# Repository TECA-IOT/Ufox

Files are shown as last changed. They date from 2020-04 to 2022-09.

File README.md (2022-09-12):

# 1. Ufox devkit Sigfox RC4
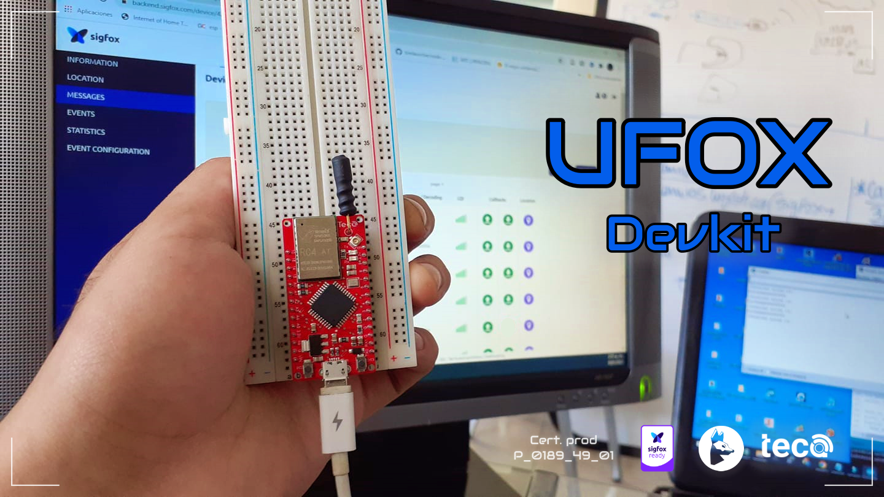
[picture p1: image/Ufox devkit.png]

Kit de desarrollo Sigfox para región RC4: 
-Argentina, Chile, Colombia, Costa Rica El Salvador, Panamá, Guatemala, Honduras, Nicaragua, Panama, Perú, Trinidad & Tobago, Uruguay, Paraguay.
Asia pacifico: 
Australia, Hong Kong, Indonesia, Malasia, Nueva Zelanda, Singapure, Taiwán, Thailandia.

## 1.1 Visita la Wiki Ufox: Documentación y ejemplos avanzados
`<link>` : <https://github.com/TECA-IOT/Ufox/wiki>
### 1.1.1 API librería ufox.h
`<link>` : <https://github.com/TECA-IOT/Ufox/wiki/API>
### 1.1.2 Manual Técnico
`<link>` : <https://github.com/TECA-IOT/Ufox/wiki/Manual-T%C3%A9cnico>
### 1.1.3 Enviar múltiples variables en mensaje sigfox con función sprintf
`<link>` : <https://github.com/TECA-IOT/Ufox/wiki/Funci%C3%B3n-Sprintf>
### 1.1.4 Librería Fritzing
`<link>` : <https://github.com/TECA-IOT/Ufox/wiki/Libreria-de-ufox-para-Fritzing>
### 1.1.4 Guía de inicio rápido
`<link>` : <https://github.com/TECA-IOT/Ufox/wiki/Gu%C3%ADa-de-inicio-r%C3%A1pido>

### 1.1.5 SHIELD UFOX INFORMACION:
`<link>` : <https://github.com/TECA-IOT/Shield-Ufox>

## 1.2 Caracteristicas

- Microcontrolador Atmega32U4 USB y Modem Wisol WSSFM10R4 RC4 .
- Programable con Arduino IDE (compatible con pines de arduino Leonardo, ProMicro, Micro, y otras placas arduino basadas en el micro atmega32U4).
- Incluye una antena interna helicoidal  de 3 Dbi y opcionalmente un conector  UFL para antenas externas. (se recomienda previamente desoladar la antena helicoidal para su uso). 
- Alimentación desde fuente USB 5V con voltaje de operación interno de 3.3V.
- Ideal para desarrollar prototipos y aplicaciones de forma rapida y sencilla, incluye un microcotrolador Atmega32U4  compatible con arduino.
- Cuenta con un regulador de voltaje de 3.3V AMS1117  suministra  hasta 1 amperio de corriente.
- Diseño compacto, seguro y de bajo consumo
- Comunicación serial por Hardware (Serial1 Arduino) dedicado exclusivamente para comunicacion con modem Wisol.
- Reset de modulo Wisol Conectado al Pin "12" Arduino. 
- Botón de proposito general programable en el pin "13" Arduino
- Pines Digitales, Analogicos, PWM, comunicacion SPI, I2C,Interrupcion externa, Serial.
- informacion acerca de arduino leonardo: 
`<link>` : <https://store.arduino.cc/usa/leonardo>

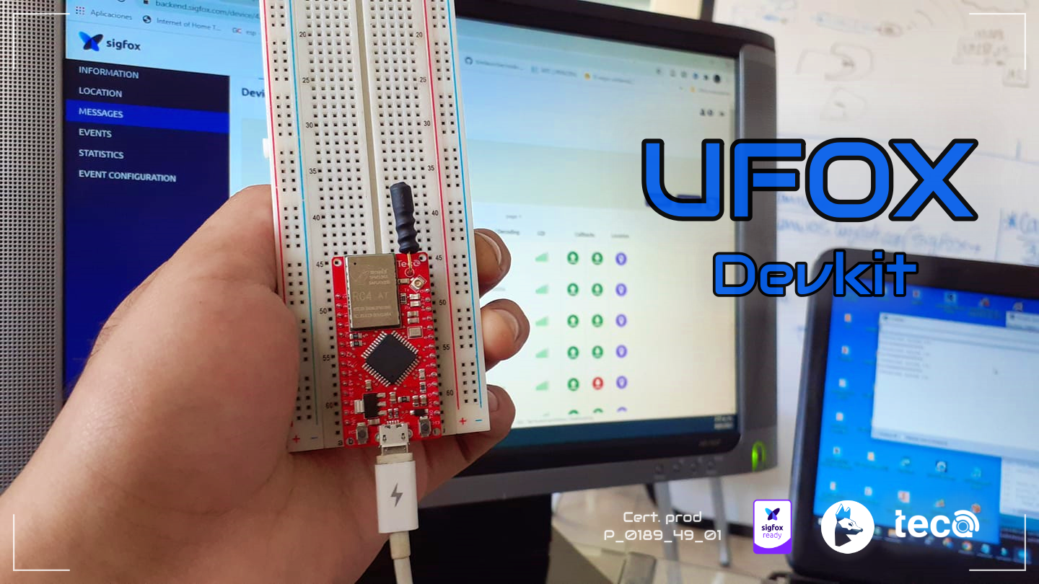
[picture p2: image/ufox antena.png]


## 1.3 Caracteristicas 
### 1.3.1 Electricas 

| Descripcion (1*)| Unidad |
| --- | --- |
| Voltaje entrada USB (Conector micro USB)|  5 Voltios |  
| Voltaje Mínimo entrada (Pin VIN) |  3.7 Voltios |  
| Voltaje Máximo  entrada (Pin VIN) |  9 Voltios |  
| Corriente máxima | 1A |
| Voltaje de funcionamiento interno típico  |  3.3 Voltios  | 

| Descripcion (2*)| Unidad |
| --- | --- |
| Voltaje Máximo absoluto entrada (Pin 3.3V) |  4 Voltios |  
| Voltaje Mínimo absoluto entrada (Pin 3.3V) |  2.7 Voltios  |  

- Notas(*)
- (1*) Referente a la Entrada de voltaje por el Pin "VIN" o por el conector micro USB. Este voltaje ingresa por el regulador interno, el regulador suministrara a su salida 3.3 Voltios alimentando a toda la electrónica interna. El voltaje regulado se ve reflejado en el Pin "3.3V".
- (2*) Referente a la entrada de voltaje en el Pin "3.3V" para el  caso donde no exista entrada de voltaje por el pin "VIN". Este voltaje es suministrado sin proteccion directamente a toda la electronica interna. Esta forma de alimentar puede ser útil cuando se requiera emplear baterias. (Se recomienda agregar un diodo en serie)

### 1.3.2 Radiofrecuencia
| Descripcion | Unidad |
| --- | --- |
| Antena helicoidal | 3 DBi |
| Frec. Uplink | 920.8 MHz |
| Frec. Downlink | 922.3 MHz |
| Data rate | 600bps |
| Potencia RF | +22dbm 0,2045W máx |
| Modulación | DBPSK |
| Técnica de transmisión | FHSS |
| Técnologia de transmisión | UNB (Ultra narrow band) - Sigfox |
| Canales de transmisión | 54 canales (9 macro-canales x 6 micro-canales) |

## 1.4 Descripcion de pines Ufox

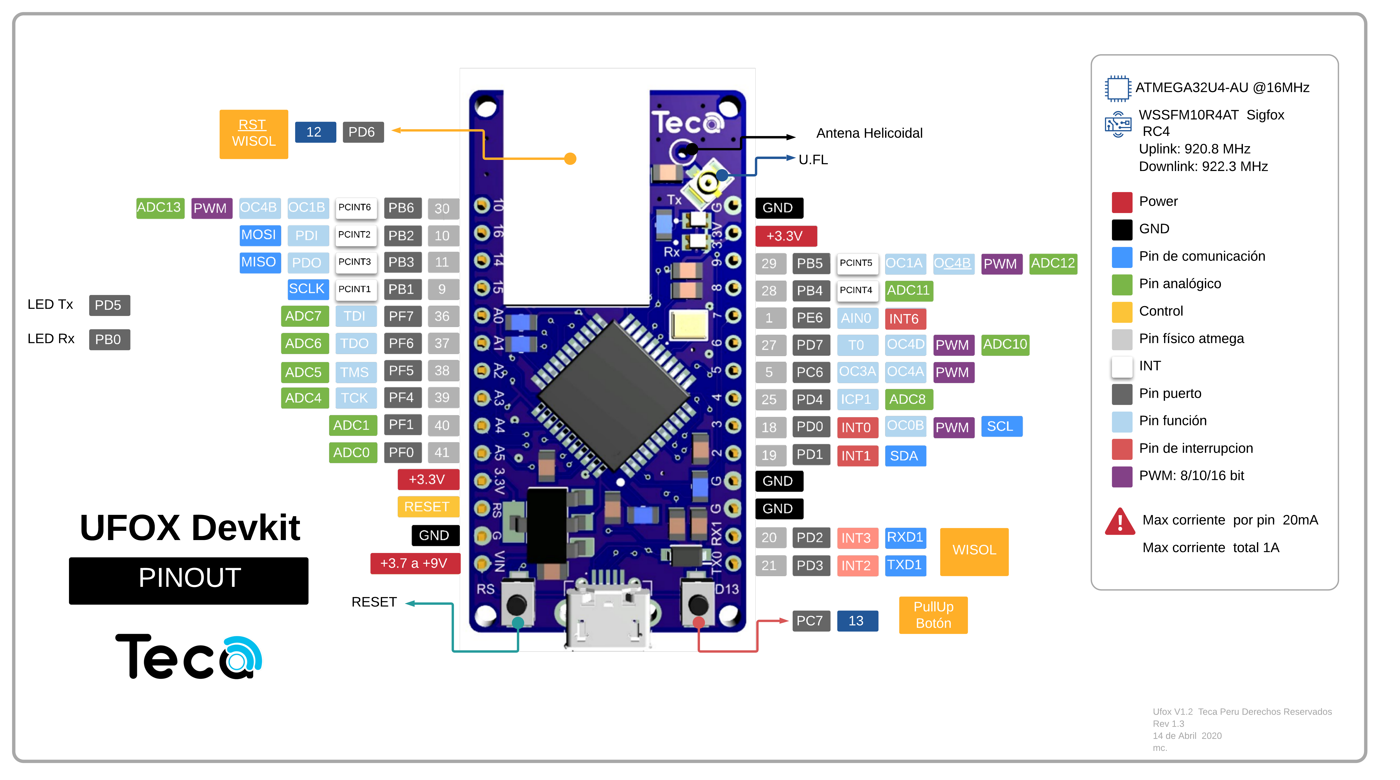
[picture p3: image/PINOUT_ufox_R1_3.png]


# 2. Cargar un Sketch a Ufox
- Enchufe el cable usb con el conector micro usb de Ufox, luego conectar a su PC
- Espere a que su PC  reconosca a Ufox (el reconocimiento es instantaneos para SO Window ,7,8,10).
- Abra el Ide Arduino.
- Puede cargar un  ejemplo de inicio  como el siguiente:

## 2.1 Blink Ufox
Ufox dispone de 2 led de señalizacion Serial Tx y RX, el usuario puede hacer uso de estos led, en este ejemplo se muestra como hacer uso de ellos.

```javascript

int RXLED = 17;  // El RXLED (AZUL) tiene un pin Arduino definido con numero 17

void setup()
{
  pinMode(RXLED, OUTPUT);  //LED RX como salida
}

void loop()
{
  digitalWrite(RXLED, LOW);   // encender RXLED 
  TXLED0;                   //  apagar TXLED
  delay(500);                 // Esperar un segundo
  digitalWrite(RXLED, HIGH);    // apagar el RXLED
  TXLED1;                     //TXLED macro, encender TXLED 
  delay(500);                 // Esperar un segundo
}
```

- Selecciones la placa Arduino Leonardo y seleccion el puerto COM detectado en su PC.
- Y cargue el sketch.

blink ufox

## 2.2 Comuncación Serial con modem Wisol
*El modem Wisol WSSFM10R4AT puede comunicarse mediante puerto serial1 a 9600 baudios, con una sintaxis definida con comando "AT", puede consultar mas informacion de comandos en la hoja de datos (datasheet). El modem trabaja a una frecuencia de 920MHZ Uplink y 922 Dowlink. Consulte mas informacionde como activar el mdem en la platafoma de sigfox o con su operador sigfox Local : Aqui 

```javascript
void setup() {
  Serial.begin(9600);
  Serial1.begin(9600);
}

void loop() {
   while (Serial.available()) {
    Serial1.write(Serial.read());
  }
  while (Serial1.available()) {
    Serial.write(Serial1.read());
  }
  
}
```

- Una vez cargado el sketch abra la terminal serial a 9600 baudios, seleccionar la opcion "Nueva línea".
- Escribir el comando "AT",presionar  enter, y a continuacion el chip wisol respondera con un "Ok"  
- Comandos de interes:
- ID:          AT$I=10
- PAC:         AT$I=11
- Voltaje:     AT$V?
- Temperatura: AT$T?

COMANDOS AT UFOX

## 2.3 Enviar mensaje sigfox mediante comandos AT
Enviar un mensaje a backend sigfox sera el siguiente: 255 decimal, SIGA LA SECUENCIA DE COMANDOS SIGUIENTE:
- AT$GI?
- AT$RC
- AT$SF=FF

COMANDOS AT UFOX SEND

## 2.4 Cómo registrar dispositivos a la red Sigfox
-  Obtenga un dispositivo SIGFOX ReadyTM (hardware).
- Obtenga el par de código ID/PAC de los dispositivos (extraible en el modem del dispositivo).
- Firme un contrato de suscripción con SIGFOX.
- Obtenga el inicio de sesión de SIGFOX Cloud (Backend Sigfox).
- Registre sus objetos con ID / PAC.
 Sus dispositivos están listos para la comunicación.
 
 ### Activación por Buy Sigfox
 - Disponible sólo para paises de: Colombia, Ecuador, Uruguay, Costa Rica, El Salvador, Panamá, 
 - Ingresar a la pagina  Buy Sigfox, Activate my devkit, Seleccionar su País e introducir los codigos ID y PAC: `<link>` : <https://buy.sigfox.com/activate> 
 
 ### Activación por contrato directo:
 - Para el resto de Paises. Contactarse por nuestro correos:  <gerencia.tecaperu@gmail.com> ó   nuestra pagina web <https://teca.pe> ó redes sociales <https://www.facebook.com/TecaIoTPeru>
 
#### 2.4.1 GLOSARIO
- ID : Identificador del dispositivo de 4 bytes (Es único)
- PAC :Código de autorización de transferencia de 8 bytes (Válido una vez). PAC es el certificado de propiedad del objeto, es requerido por la plataforma SIGFOX para validar las solicitudes de registro / transferencia de equipos. Una vez utilizado, la validez del código expira y se asigna un nuevo código.
- El PAC se proporciona en la venta del dispositivo (EXTRAIBLE DEL MODULO RF)
 - Ejemplo: 006D8AF2; 10708756FE9515D5  

# 3. LIBRERÍA UFOX ARDUINO | librería Sigfox
La libreria ufox incorpora una serie de funciones y metodos que simplifican la conexion a la red de sigfox. Instale la libreria Ufox  en el IDE de arduino descargando este repositorio, existen diversos modos de instalar libreria externas, 
## 3.1 Instalación
### 3.1.1 Opción 1: 
- Descomprima este repositorio descargado en formato .ZIP y copie la carpeta dentro de :  [Unidad]:\Users\[usuario]\Documents\Arduino\libraries
### 3.1.2 Opción 2: 
- Desde el mismo IDE Arduino dirijase a Programa, Incluir  Libreria, Añadir biblioteca  .ZIP . Localice el repositorio descargado y abrir.
- Una vez instalado recargue el  Ide arduino y podra ver que la libreria y ejemplo se muestran: 
### 3.1.3 Opción 3:
- Abrir el IDE Arduino, y desde el gestor de descargas de Librerias de Arduino descargar buscar "ufox" y descargarlo.
descargar libreria ufox

## 3.2 Enviar un Mensaje Simple con librería Ufox.h

En este ejemplo puede enviar un mensaje numérico cada vez que el botón 13 (ubicado al lado derecho del devkit), es presionado. Tener en consideración que los mensajes Sigfox son enviados en formato de hexagesimales con un tamaño  máximo de 12 bytes de carga útil (Payload), todos los valores numéricos serán convertidos a valores hexagesimales de forma automatica por librería. Elija el ejemplo llamado "Simple_uplink". 
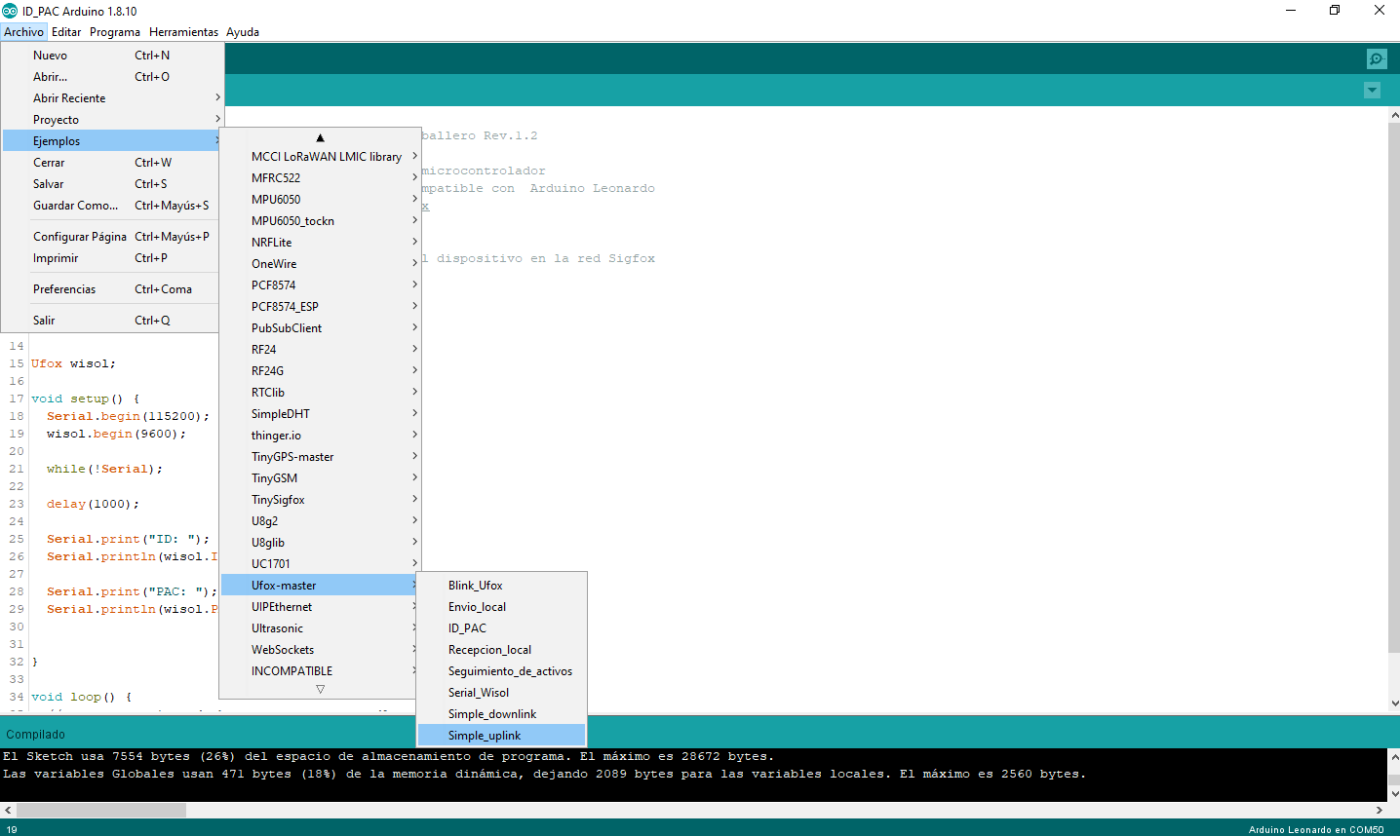
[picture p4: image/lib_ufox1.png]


```javascript
#include <Ufox.h>

#define btn   13
#define RXLED  17 

Ufox wisol;

void setup() {
  pinMode(btn,INPUT);
  pinMode(RXLED,OUTPUT);
  
  Serial.begin(115200);
  wisol.begin(9600);

  while(!Serial);  //comentar si usará una fuente de energía externa

 Serial.println("-Presione botón 13-");
}

void loop() {
  
  if(digitalRead(btn)==0){

    digitalWrite(RXLED,LOW);
    wisol.RST();
    
    uint32_t valor =random(0,15);
    Serial.println(wisol.SEND(valor));

    //String valor2 ="10";
    //Serial.println(wisol.SEND(valor2));
    
    digitalWrite(RXLED,HIGH);
    wisol.SLEEP();
    delay(3000);
    Serial.println("-Presione botón 13-");
  }  
}
```

###

###
- La información podrá vizualizarse en el backend de Sigfox. Usted previamente debe tener asociado a su cuenta el devkit Ufox con un contrato de conectividad. Se mostrara el ID de su dispositivo asociado y el nuevo codigo PAC que has sido generado tras la activación del contrato.
- El Backend de Sigfox es la plataforma para poder gestionar las conexiones de sus dispositivos. La configuración mas importante a consideracion son los Callbacks, donde podra redireccionar los mensajes por medio de HTTP o HTTPS a otros servidores, o tambien redireccionarlos a AWS IOT Core, Azure e IBM.

Simple uplink Ufox - backend sigfox

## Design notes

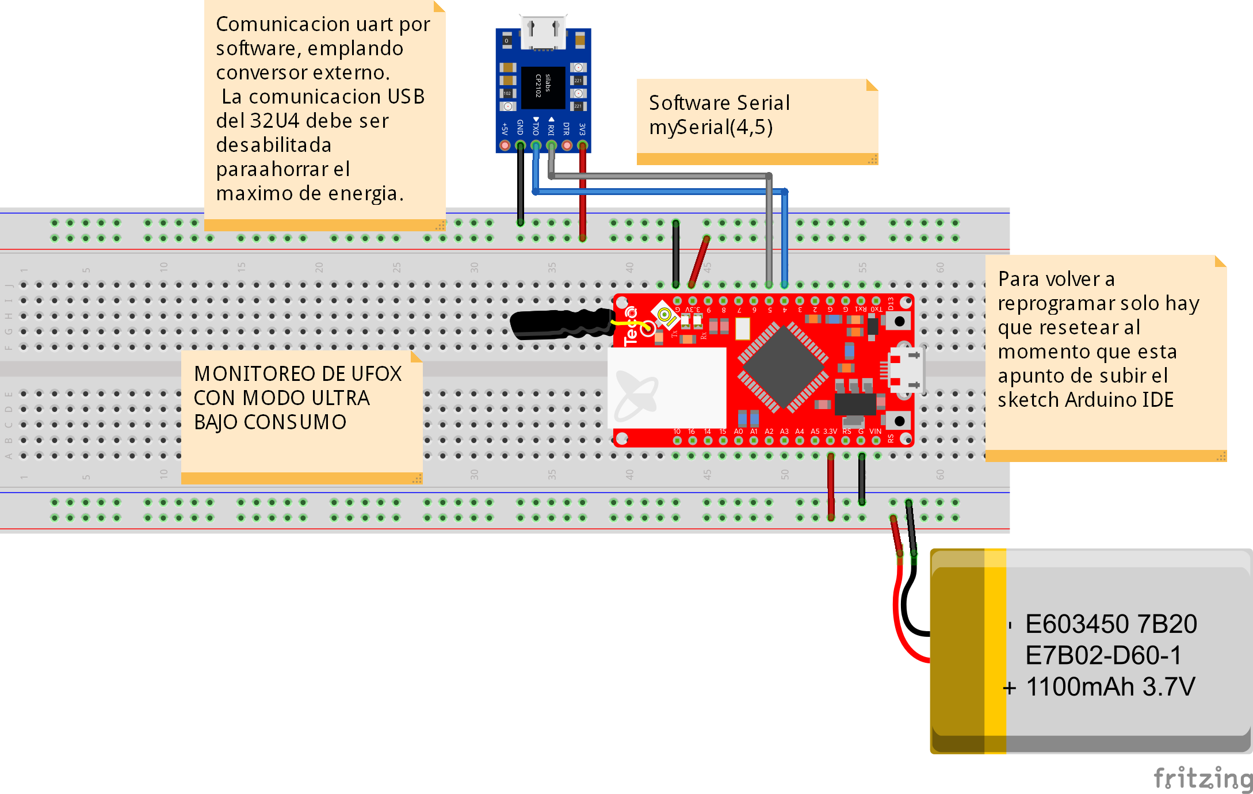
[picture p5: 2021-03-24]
image/ufox_lowpower_battery_bb.png

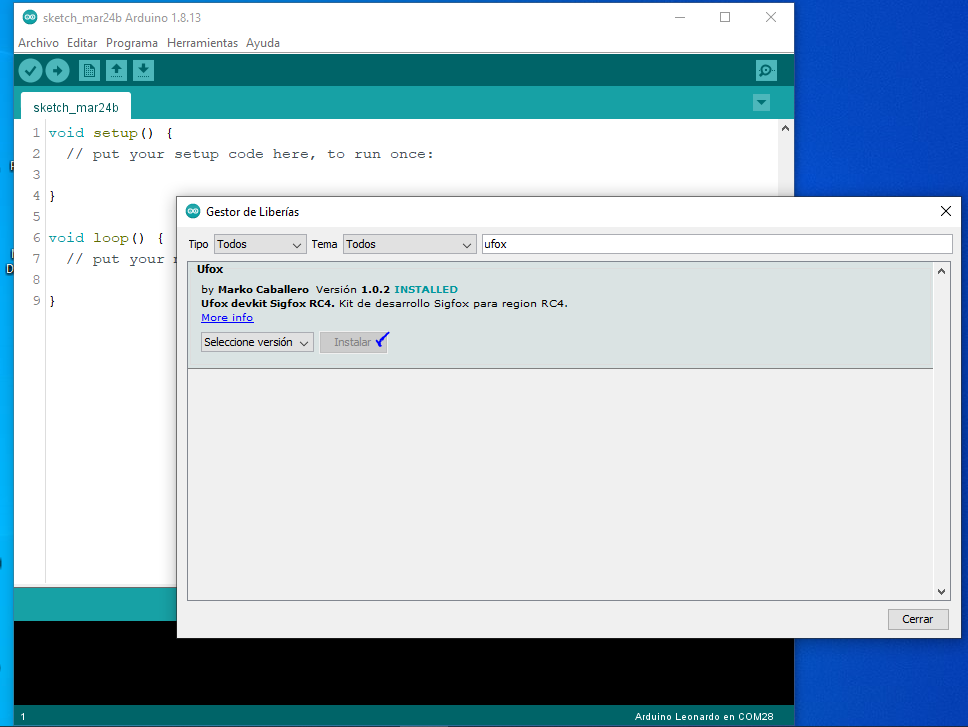
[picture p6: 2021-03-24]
image/ufox descargar lib.PNG

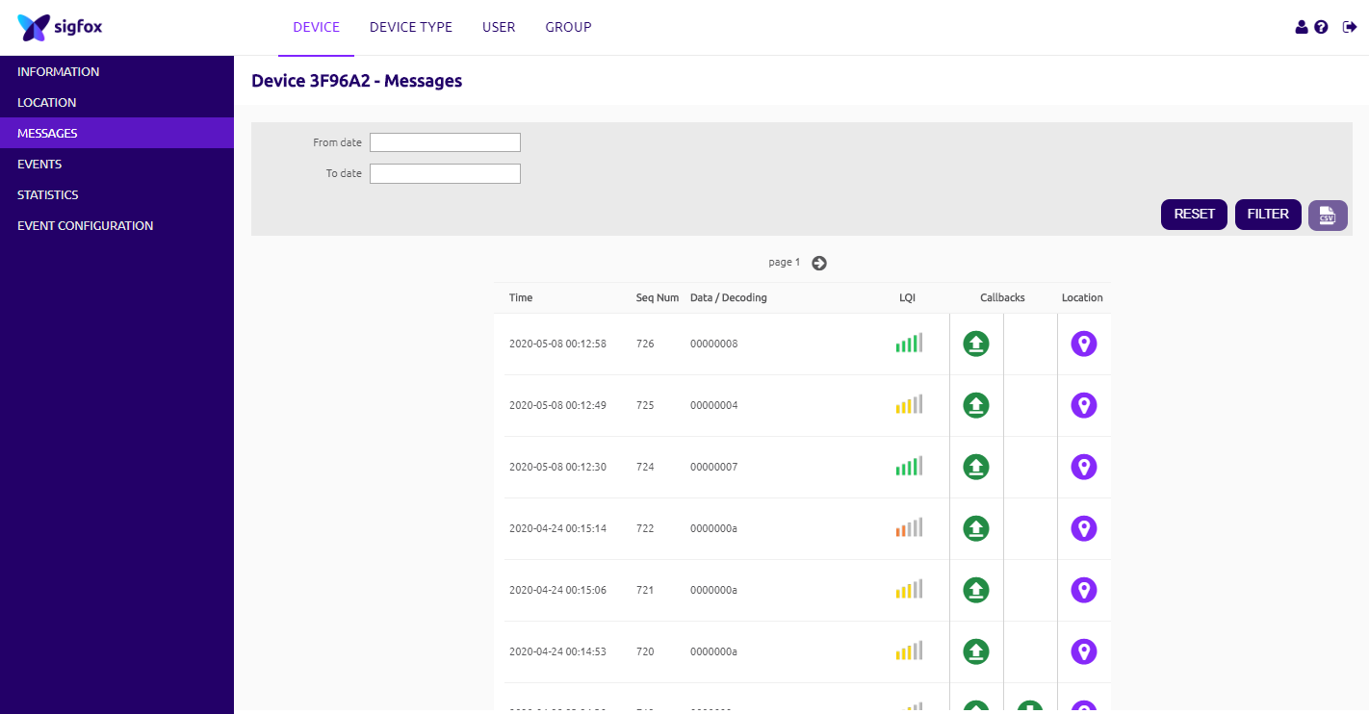
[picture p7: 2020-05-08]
image/wewe.png

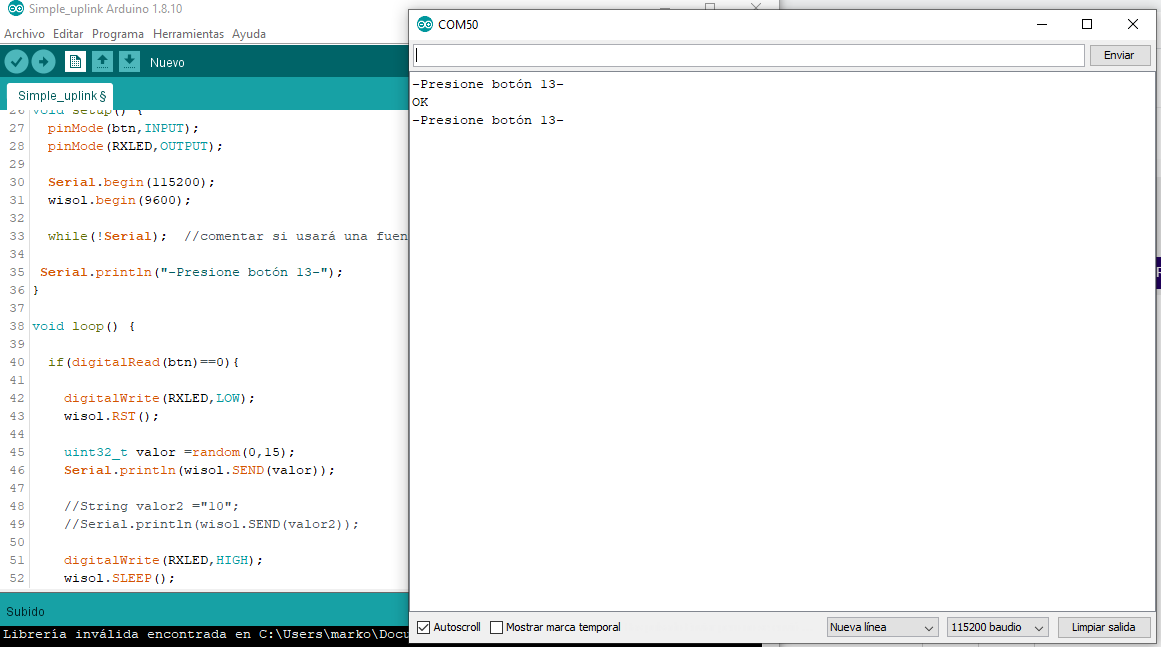
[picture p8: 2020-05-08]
image/qwrw.PNG

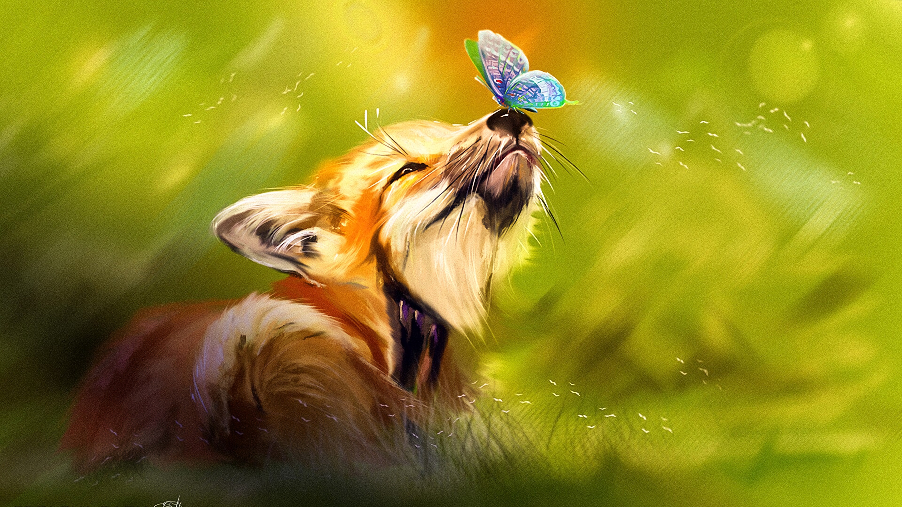
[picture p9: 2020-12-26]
image/Ufox lib.jpg

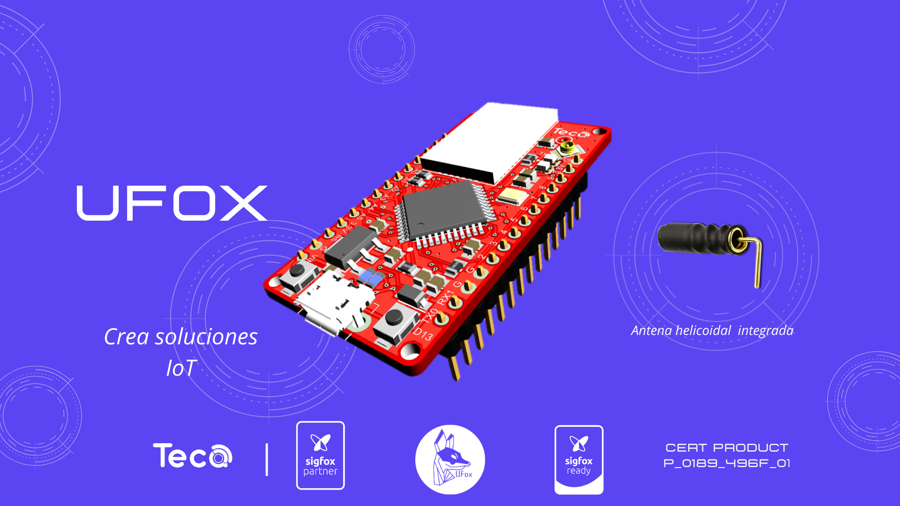
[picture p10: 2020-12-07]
image/ufox antena - copia.png

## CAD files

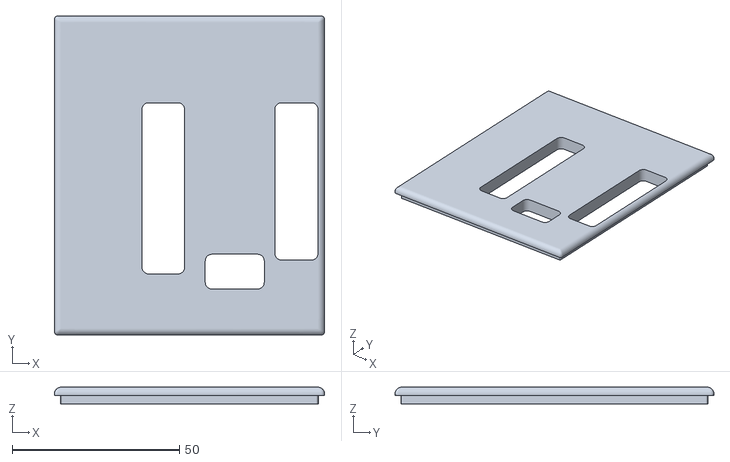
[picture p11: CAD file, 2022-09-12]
Case 3D/VERSION 1.0/STL/TAPA CASE UFOX.stl
80.8 x 95.4 x 5.00

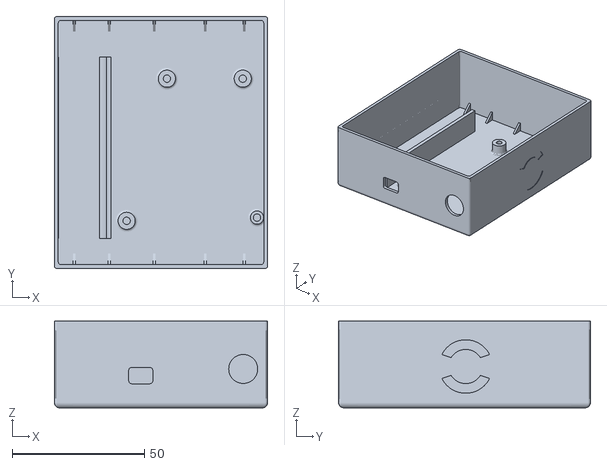
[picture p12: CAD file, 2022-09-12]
Case 3D/VERSION 1.0/STL/CASE UFOX.stl
80.8 x 95.4 x 32.8

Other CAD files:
Case 3D/VERSION 1.0/EDITABLES/CASE UFOX.ipt
Case 3D/VERSION 1.0/EDITABLES/TAPA CASE UFOX.ipt

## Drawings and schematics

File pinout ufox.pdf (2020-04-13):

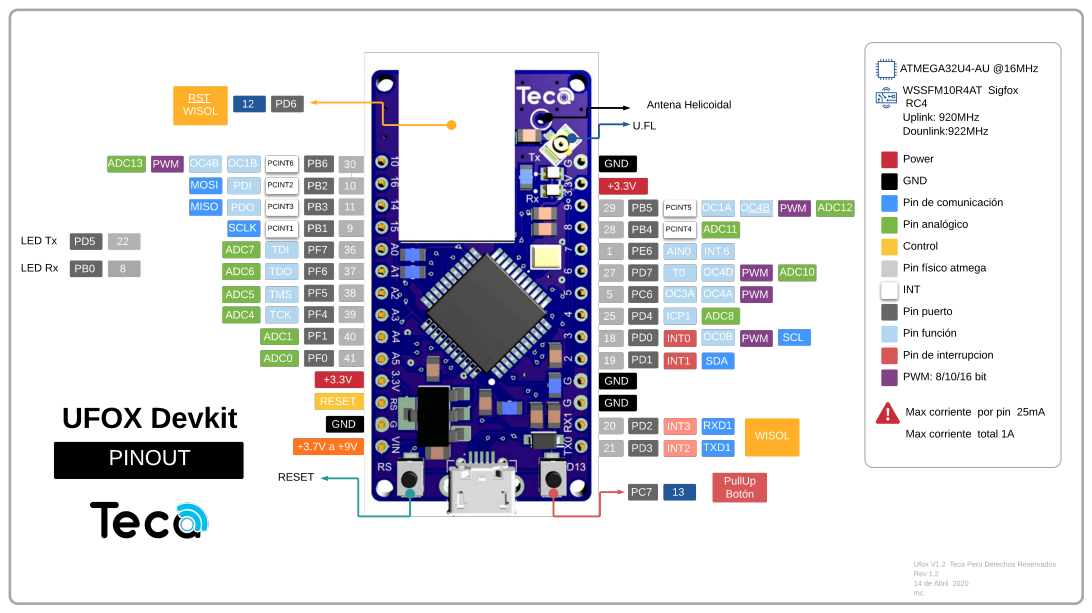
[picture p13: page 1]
RESET; UFOX Devkit; PINOUT; RST WISOL; WISOL; PullUp; Botón; ATMEGA32U4-AU @16MHz; WSSFM10R4AT Sigfox RC4 Uplink: 920MHz Dounlink:922MHz; Antena Helicoidal; LED Tx; LED Rx

Power
GND
Pin de comunicación
Pin analógico
Control
Pin físico atmega
INT
Pin puerto
Pin función
Pin de interrupcion
PWM: 8/10/16 bit

Max corriente por pin 25mA
Max corriente total 1A

Ufox V1.2 Teca Peru Derechos Reservados
Rev 1.2
14 de Abril 2020

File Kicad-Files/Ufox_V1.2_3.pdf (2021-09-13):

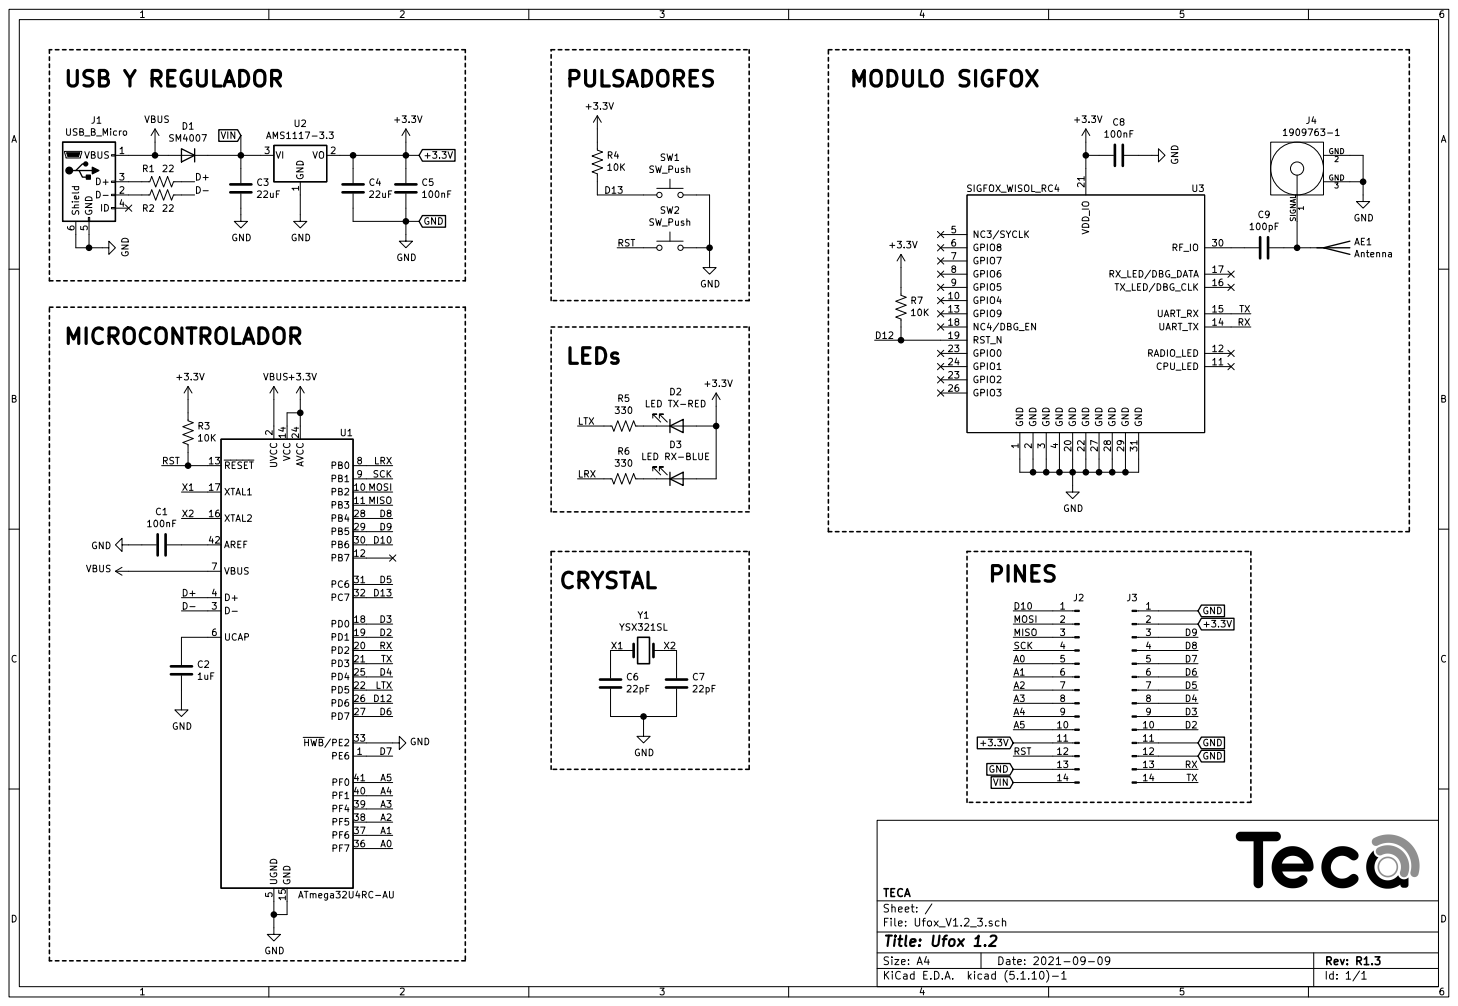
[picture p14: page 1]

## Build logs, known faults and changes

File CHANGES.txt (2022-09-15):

1.2
    * Uso para modem WSSFM10R4 Sigfox regin RC4
    * Funciones basicas de comunicacion en inicializion de modem
    * metodo SEND y SEND_RCV  envian y retornan strings.
    * metodo comand para interactuar directamente con comandos at
1.5
    * Actualizacion de ejemplos

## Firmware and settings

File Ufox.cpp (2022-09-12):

/*
Derechos Reservados "Teca" 2020, autor Marco A. Caballero Rev.1.2
*/
#include "Ufox.h"
#include "Arduino.h"

//uint8_t pin_rst_wisol=12; // pin 12 como reset wisol

//#define baud_ws 9600

//String ATS = "AT$";
//String ENV = "env:> ";
//String RCV = "<rec: "; 

//char cadena_cad[40]= " ";
//uint8_t i = 0;
//char caracter = 0x00;

Ufox::Ufox() {
  dbg = false;
}

Ufox::Ufox(bool _dbg) {
  dbg = _dbg;
}

Ufox::Ufox(bool _dbg,uint8_t _rst_ws) {
  dbg = _dbg;
  pin_rst_wisol=_rst_ws;
}

void Ufox::debug(bool _dbg) {
  dbg = _dbg;
}

void Ufox::begin(uint16_t _baudio) {
  baudio = _baudio;
  pinMode(pin_rst_wisol, OUTPUT);
  Serial1.begin(baud_ws );
  digitalWrite(pin_rst_wisol, LOW);
  delay(100);
  digitalWrite(pin_rst_wisol, HIGH);
  delay(100);
  if (dbg) {
    Serial.begin(baudio);
    // while (!Serial);
  }
}

String Ufox::command(String _cmd) {
  cmd = _cmd;
  if (dbg) {
     Serial.begin(baudio);
     //while (!Serial);
  }

  if (dbg){ Serial.print(ENV);Serial.println(cmd);}

 //Serial.println(cmd);
  long lastMsg = millis();
  caracter = 0x00;
  i = 0;
 for(int a=0;a<40;a++){cadena_cad[a]= 0x00;}
  Serial1.println(cmd);
  do{
       long now = millis();
       if(now - lastMsg > 70000){
           break;
       }
      if(Serial1.available()){
         caracter = Serial1.read();
        if(i>40){
          delay(300);
          while( Serial1.available() ){ Serial1.read(); }
          cadena_cad[0] = 0x00;
          return "ERROR: OVERFLOW!!!";
        }
         cadena_cad[i] = caracter;
        i++;
      }
   } while (caracter != 0x0A);
  delay(10);
  lastMsg = millis();
  do{
     long now = millis();
     if(now - lastMsg > 70000){
          break;
       }
     if(Serial1.available()){
        caracter = Serial1.read();
        if(i>40){
          delay(300);
          while( Serial1.available() ){ Serial1.read(); }
          cadena_cad[0] = 0x00;
          return "ERROR: OVERFLOW!!!";
        }
        cadena_cad[i] = caracter;
        i++;
    }
   }while (caracter != 0x0A);
  cadena_cad[i] = 0x00;
  cadena_cad[i- 1] = 0x00;

  if (dbg) {Serial.print(RCV);Serial.println(cadena_cad); }
  caracter = 0x00;
  //Serial.println( strlen(cadena_cad));
  return cadena_cad;
}

String Ufox::command2(String _cmd) {
  cmd = _cmd;
  if (dbg) {
    Serial.begin(baudio);
   // while (!Serial);
  }
  if(dbg){ Serial.print(ENV);Serial.println(cmd);}

  caracter = 0x00;

  i = 0;
  uint32_t t = 0;
  for(int a=0;a<40;a++){cadena_cad[a]= 0x00;}
  Serial1.println(cmd);
  //Serial.println(cmd);
  long lastMsg = millis();
  while (true)
  {
    long now = millis();

    if(Serial1.available()) {
       caracter = Serial1.read();
       if(caracter == 0x0D)caracter = ' ';
       if(caracter == 0x0A)caracter = ' ';
       cadena_cad[i] = caracter;
       //Serial.print(caracter);
       i++;
    }
    if (now - lastMsg > 60000) {
      //Serial.println("salio");
      break;
    }
    if(i==32){
      if(cadena_cad[0]=='O') break;
    }
    if(i==37) break;

  }
  //Serial.println(t);
  //Serial.println(i);
  if (i == 32) {
    cadena_cad[0] = ' ';
    cadena_cad[1] = ' ';
    cadena_cad[2] = ' ';
    char cadena_cad2[35];
    int c = 0;
    for ( c = 0; c <= i - 7; c++) {
      cadena_cad2[c] = cadena_cad[c + 7];
    }
    for ( c = 0; c < sizeof(cadena_cad); c++) {
      cadena_cad[c] = 0x00;
    }

 int k=0,j=0;
 while (cadena_cad2[k]!='\0') 
 {
  if(cadena_cad2[k]!=' ')
  {
   cadena_cad[j]=cadena_cad2[k];
   j++;
  }
  k++;
 }
    //Serial.println(cadena_cad2);
   // Serial.println(cadena_cad);
  }
    //delay(100);
    if (dbg) {Serial.print(RCV);Serial.println(cadena_cad);} 
    caracter = 0x00;
    return String(cadena_cad);
  }

  String Ufox::ID() {
    return Ufox::command(ATS + "I=10");
  }

  String Ufox::PAC() {
    return Ufox::command(ATS + "I=11");
  }

  uint16_t  Ufox::TEMP() {
    return String(Ufox::command(ATS + "T?")).toInt();
  }

  uint16_t  Ufox::VOLT() {

    return  String(Ufox::command(ATS + "V?")).toInt();
  }

  void Ufox::RST() {
    digitalWrite(pin_rst_wisol, LOW);
    delay(100);
    digitalWrite(pin_rst_wisol, HIGH);
    delay(100);
  }

  String Ufox::SLEEP() {
    return Ufox::command(ATS + "P=2");
  }

  String Ufox::SEND(uint32_t _dataint) {
    dataint = _dataint;
    Ufox::command(ATS + "GI?");
    Ufox::command(ATS + "RC");
    char cadena_cad[15] = "";
    sprintf(cadena_cad, "SF=%08lx", dataint);
    return Ufox::command(ATS + cadena_cad);
  }
  
 String Ufox::SEND(String _datastr) {
    datastr = _datastr;
    if (datastr.length() > 24) return ("error");
    if (datastr.length() % 2 != 0)datastr = "0" + datastr;
    Ufox::command(ATS + "GI?");
    Ufox::command(ATS + "RC");
    return Ufox::command(ATS + "SF=" + datastr);
  }
  
  String Ufox::SEND_RCV(uint32_t _dataint_rcv) {
    dataint_rcv = _dataint_rcv;
    Ufox::command(ATS + "GI?");
    Ufox::command(ATS + "RC");
    char cadena_cad[20] = "";
    sprintf(cadena_cad, "SF=%08lx,1", dataint_rcv);
    return Ufox::command2(ATS + cadena_cad);
  }

   String Ufox::SEND_RCV(String _datastr_rcv) {
    datastr_rcv = _datastr_rcv;
    if (datastr_rcv.length() > 24) return ("error");
    if (datastr_rcv.length() % 2 != 0)datastr_rcv = "0" + datastr_rcv;
    Ufox::command(ATS + "GI?");
    Ufox::command(ATS + "RC");
    char cadena_cad[20] = "";
    return Ufox::command2(ATS + "SF=" + datastr_rcv+",1");
  }

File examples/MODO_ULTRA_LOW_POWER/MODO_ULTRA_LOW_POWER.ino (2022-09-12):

//UFOX EN MODO DE AHORRO MAXIMO DE ENERGIA
//CON BATERIA DE 2800mAH (18650-litio) PUEDE LLEGAR A DURAR HASTA 30 DIAS.
//POR: MARCO ANTONIO CABALLERO MORENO
//V1 21/03/21
///*********************************************
//ESTE EJEMPLO MUESTRA UN METODO PARA PONER A UFOX EN UN MODO DE BAJO CONSUMO EXTREMO.
//LA COMUNICACION USB ES DESABILITADA PARA AHORRAR LO MAXIMO EN ENERGIA.
//ES POSIBLE SEGUIR CONTADO CON COMUNICACION SERIAlPARA USUARIO, EMPLEANDO UN PIN DIGITAL, PARA ESTE EJEMPLO EL 5,
//USANDO LA LIBRERIA SOFTWARE SERIAL DE ARDUINO. SE REQUIERE UN MODULO CONVERSOR USB A SERIAL
//EXTERNO COMO: FTDI,CP2102, CH340, ETC..
//
//LA LIBRERIA ARDUINO LOW POWER https://github.com/rocketscream/Low-Power, POR ROCKETSCREAM. PROPORCIONA UN METODO 
//SIMPLE PARA ACCERDER A LOS MODOS DE BAJO CONSUMO DEL ATMEGA32U4, ES POSIBLE TEMPORIZAR HASTA UN MAXIMO DE 8 
//SEGUNDOS EN MODO SUSPENSION ALMACENANDO VARIABLES EN RAM, ESTO RESULTA UTIL PARA EJECUCION CONTINUA Y 
//TRANSMISION DE DATOS TEMPORIZADOS SIN REQUERIR A ELECTRONICA ADICIONALES O MODULOS EXTERNOS.
//LA TECNICA EMPLEA UNA VARIABLE CONTADORA "val" QUE SE USA PARA DECIDIR SI ES TIEMPO DE REALIZAR LAS TAREAS O
//PERMANER ESTADO DE SUSPENCION
//EL DISPOSITIVO NO SE REINICIARA LUEGO DE SALIR DEL MODO SUSPENSION, ES DECIR TODAS LAS
//EJECUCIONES SE SEGUIRAN REALIZANDO DENTRO DE LA FUNCION LOOP

//PROBLEMAS CONOCIDOS: Podria ocurrir que el devkit deje de responder al volverle a cargar el codigo, 
//esto puede darse porque se desabililita la comunicacion por USB para el ahorro de energia, el bootloader ARDUINO permite que al momento 
//de un reinicio fisico se establesca un tiempo de 5 segundos en donde se pueda volver a grabarse un 
//codigo de forma normal (podria cambiar el puerto COM) puede aprovechar ese corto tiempo para volver a grabar y restaurar 
//su funcionamiento normal con algun otro sketch. Pruebe tambien reiniciando el IDE ARDUINo y SU PC.

#include <LowPower.h>
#include <SoftwareSerial.h>
#include <Ufox.h>

#define RXLED  17 
#define LED  9 

SoftwareSerial mySerial(4, 5); //(RX,TX)

Ufox ufox;

int val=0; //variable contador
int addr=0; //direccion eeprom
float tmp = 83 ; //tiempo que permanecera apagado (Minutos) =  82 *8/60 = 10.9 min

void setup()
{
  delay(3000);
  //Serial.begin(9600); 
  mySerial.begin(9600); //iniciar serial de usuario pin 5-TX
  ufox.begin(9600); //iniciar radio ufox
  mySerial.println("Iniciando Dispositivo Ufox!");

  //while(!Serial);  //es necesario comentar esta linea si usará una fuente de energía externa
  delay(100);
  
  ufox.SLEEP();
  pinMode(LED,OUTPUT);
  pinMode(RXLED,OUTPUT);
  
    for(int i=0; i<10;i++){
    digitalWrite(LED,HIGH); delay(30);
    digitalWrite(LED,LOW); delay(30);
    }
    
  TASK(); //realizar tareas, lectura de sensores, actuadores, enviar por sigfox, recibir de sigfox,etc...
  mySerial.print("Apagar UFOX (Min): ");
  mySerial.println((tmp*8)/60);
}

void loop() 
{
 val++;
 mySerial.print(".");
    
     if(val >= tmp){
     digitalWrite(LED,LOW);
     mySerial.println("Despertar UFOX! ");
     
     TASK(); //realizar tareas, lectura de sensor, actuadores, enviar por sigfox, recibir de sigfox,etc...
 
     val=0;
     mySerial.print("Apagar UFOX (Min): ");
     mySerial.println((tmp*8)/60);
     LowPower.powerDown(SLEEP_8S, ADC_OFF, BOD_OFF); //APAGAR
       }   
 LowPower.powerDown(SLEEP_8S, ADC_OFF, BOD_OFF); //APAGAR
}

void TASK(){
    ufox.RST(); //despertar radio sigfox
      digitalWrite(RXLED,LOW); //encender led
      mySerial.println("Enviar dato Sigfox...");  
      int datos = ufox.VOLT(); //leer la bateria
      mySerial.println(ufox.SEND(datos));    //enviar dato sigfox y mostrar resultado de envio
      mySerial.print("Enviando: ");
      mySerial.println(datos);  
      digitalWrite(RXLED,HIGH);
    ufox.SLEEP();//apagar modem sigfox
}

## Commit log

2020-04-23 Ufox lib Arduino Rev1.2
    Libería para interactuar con modem Wisol WSSFM10R4 y Arduino
2022-09-12 CASE 3D UFOX
    Agregando diseño de Case 3D para Ufox
    [CASE UFOX.ipt, CASE UFOX.stl, TAPA CASE UFOX.ipt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]
2022-09-12 agregando foto de case
    agregando imagen
